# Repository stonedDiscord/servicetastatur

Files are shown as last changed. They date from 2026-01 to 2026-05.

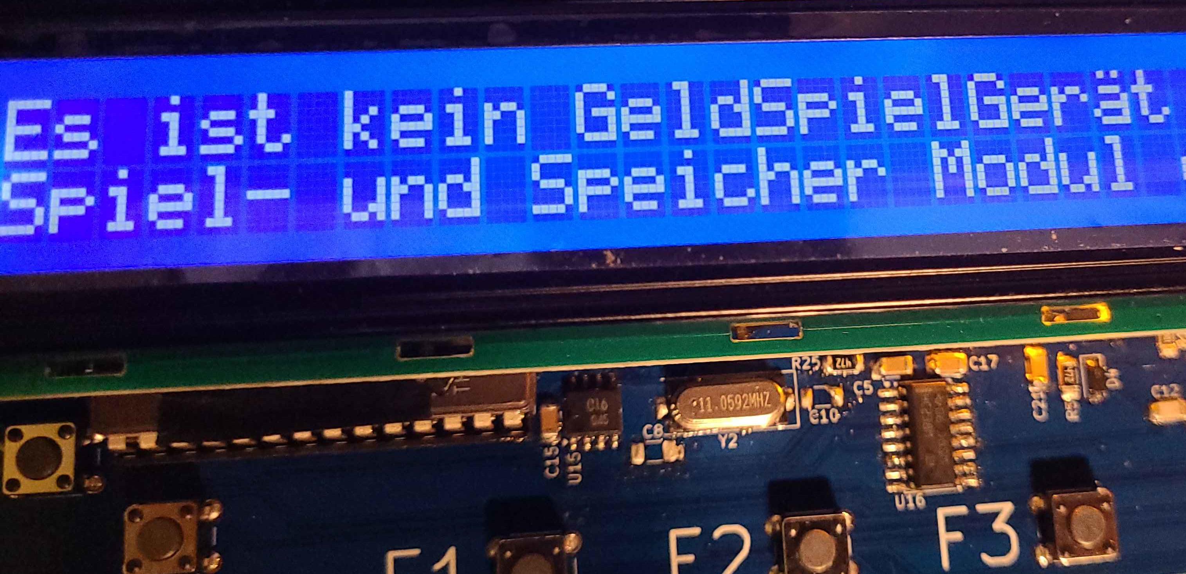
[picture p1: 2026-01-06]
photo/IMG.jpg

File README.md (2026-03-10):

# Servicetastatur

Ein Nachbau der Servicetastatur für Merkur Geräte ab Profitech 3000.

Man kann diese bei Auftragsfertigern bauen lassen,
EPROM, CPU, Display und Gehäuse müssen seperat beschafft werden.

Gehäuse ist [in Arbeit](https://github.com/stonedDiscord/servicetastatur/blob/master/case.scad),
es werden die Bibliotheken [jl_scad](https://github.com/lijon/jl_scad) und [BOSL2](https://github.com/BelfrySCAD/BOSL2) benötigt.

## Lizenz

Nachbauen und Modifizieren durch Dritte ist erlaubt, die Dokumentation inkl Schaltplan und Gerber müssen aber mit weitergegeben werden.
Die Lizenz gibt es hier auf Deutsch
https://creativecommons.org/licenses/by-sa/4.0/deed.de

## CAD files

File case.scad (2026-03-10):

include <jl_scad/box.scad>
include <jl_scad/parts.scad>
include <jl_scad/utils.scad>

$slop = 0.04;
$fn = $preview?16:48;
$attachable_dump_tree = true;
haelfte=BOT;

module button_guide(
    size = 7,
    wall = 1.2,
    h = 8,
    clearance = 0.25
){
    difference() {
        // OUTER sleeve (extends DOWN into box)
        translate([0,-1.5,0])
        cuboid(
            [size + wall*2, size + wall*2, h],
            anchor=FRONT+BOTTOM
        );

        // INNER hole
        translate([0,-0.5,-0.01])
            cuboid(
                [size + clearance, size + clearance, h + 0.02],
                anchor=FRONT+BOTTOM
            );
    }
}

sz = [183+4,57+4,24];

box_make(print=true,halves=haelfte,explode=5,hide_box=false)
{
    // rim snap
    box_shell_base_lid(sz,wall_sides=2,wall_top=1.2,rbot_inside=1,rtop_inside=1,rsides=15,rim_height=3,k=0.2,rim_snap=true) {
        // display
        box_part([TOP]) X(1.5) fwd(18) box_cutout(rect([150,15]),anchor=FRONT);

        // taster
        box_part([TOP]) X(-85) Y(14) { box_cutout(rect([6,6]),anchor=FRONT); button_guide(); } //Left
        box_part([TOP]) X(-75) Y(7)  { box_cutout(rect([6,6]),anchor=FRONT); button_guide(); } //Up
        box_part([TOP]) X(-75) Y(21) { box_cutout(rect([6,6]),anchor=FRONT); button_guide(); } //Down
        box_part([TOP]) X(-65) Y(14) { box_cutout(rect([6,6]),anchor=FRONT); button_guide(); } //Right
        
        
        box_part([TOP]) X(-34) Y(20) { box_cutout(rect([6,6]),anchor=FRONT); button_guide(); } //F1
        box_part([TOP]) X(-8)  Y(20) { box_cutout(rect([6,6]),anchor=FRONT); button_guide(); } //F2
        box_part([TOP]) X(17)  Y(20) { box_cutout(rect([6,6]),anchor=FRONT); button_guide(); } //F3
        box_part([TOP]) X(45)  Y(20) { box_cutout(rect([6,6]),anchor=FRONT); button_guide(); } //F4

        box_part([TOP]) X(77)  Y(17) { box_cutout(rect([6,6]),anchor=FRONT); button_guide(); } //OK
 
        // halter
        // lcd oben
        X(87.5)  Y(23.5) box_standoff_clamp(h=6,od=3,id=1.5,gap=2,pin_h=2);
        X(-87.5) Y(23.5) box_standoff_clamp(h=6,od=3,id=1.5,gap=2,pin_h=2);
       
        // unterschied 26.5
       
        // lcd unten
        X(87.5)  Y(-3)   box_standoff_clamp(h=16,od=3,id=1.5,gap=2,pin_h=2);
        X(-87.5) Y(-3)   box_standoff_clamp(h=16,od=3,id=1.5,gap=2,pin_h=2);
      
        // unterschied 23
      
        // board unten
        X(87.5)  Y(-26)  box_standoff_clamp(h=6,od=3,id=1.5,gap=2,pin_h=2);
        X(-87.5) Y(-26)  box_standoff_clamp(h=6,od=3,id=1.5,gap=2,pin_h=2);
        
        // kabel loch
        X(70)    Z(-6)   box_part([BACK]) box_hole(6,chamfer=1);
        
        // button wall
        X(50) Y(18) box_part([TOP],FRONT) box_wall(RIGHT,height=15,length=70,width=1,fillet=1.5,gap=0.5);
        
        // screen wall
        Y(25) box_part([TOP],FRONT) box_wall(RIGHT,height=9,length=140,width=1,fillet=1.5,gap=0.5);
        
        // screen
        box_part([TOP])
        box_preview() X(15) Y(-13) position(LEFT) cuboid([162,29,9],anchor=LEFT,edges="X");
    }
}

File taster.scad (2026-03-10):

$fn = $preview?16:48;

difference()
{
    union() {cube([6.7, 6.7, 10],center=true);
    translate([0,0,6]) cube([5.4,5.4,2],center=true);}
    translate([0,0,-4.5]) cylinder(h=1,r=2,center=true);
} 

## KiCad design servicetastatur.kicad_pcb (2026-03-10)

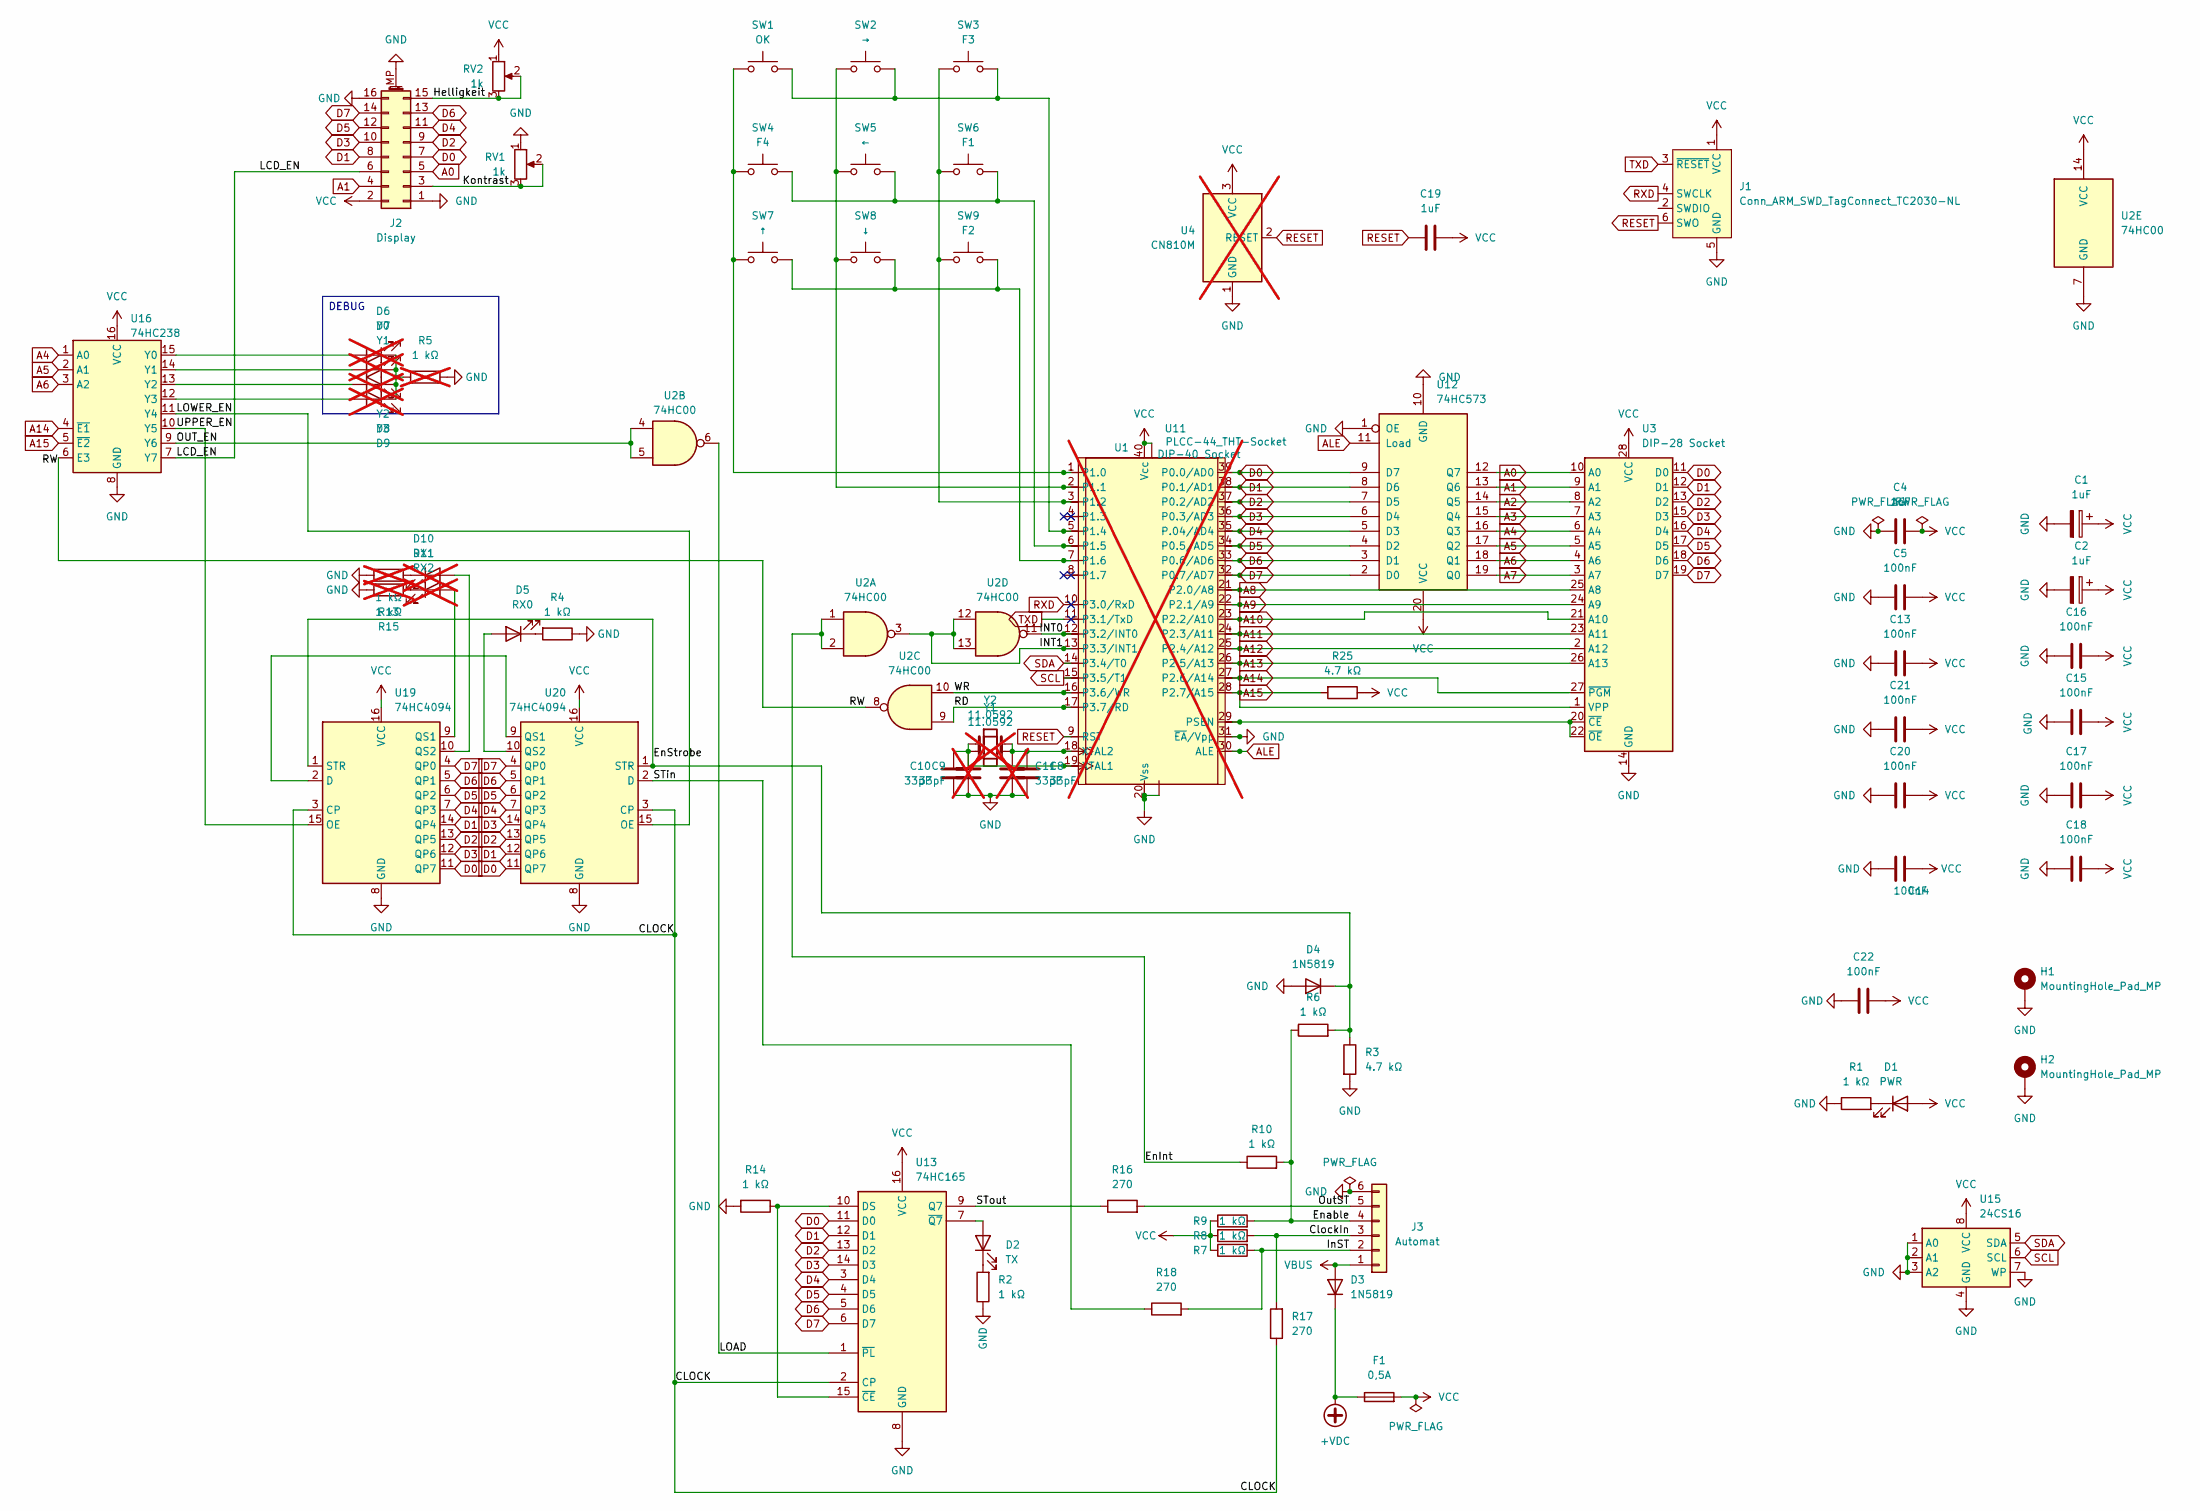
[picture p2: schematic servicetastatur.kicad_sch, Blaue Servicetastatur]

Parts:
C1, C2, C4, C19: 1uF; C_1206_3216Metric
C5, C13, C14, C15, C16, C17, C18, C20, C21, C22: 100nF; C_0603_1608Metric
C8, C10: 33pF; C_0603_1608Metric
C9, C11: 33pF; C_0603_1608Metric; not fitted
D1: PWR; LED_0805_2012Metric
D2: TX; LED_0805_2012Metric
D3, D4: 1N5819; D_SOD-123
D5: RX0; LED_0805_2012Metric
D6: Y0; LED_0805_2012Metric; not fitted
D7: Y1; LED_0805_2012Metric; not fitted
D8: Y2; LED_0805_2012Metric; not fitted
D9: Y3; LED_0805_2012Metric; not fitted
D10: RX1; LED_0805_2012Metric; not fitted
D11: RX2; LED_0805_2012Metric; not fitted
F1: 0,5A; Fuse_0805_2012Metric
H1, H2: MountingHole_Pad_MP; MountingHole 3.5mm
J1: Conn_ARM_SWD_TagConnect_TC2030-NL; Tag-Connect_TC2030-IDC-NL_2x03_P1.27mm_Vertical
J2: Display; LCDdisplay
J3: Automat; Conn01x06
R1, R2, R4, R6, R7, R8, R9, R10, R14: 1 kΩ; R_0603_1608Metric
R3, R25: 4.7 kΩ; R_0603_1608Metric
R5, R13, R15: 1 kΩ; R_0603_1608Metric; not fitted
R16, R17, R18: 270; R_0603_1608Metric
RV1, RV2: 1k; Potentiometer_Piher_PT-6-V_Vertical_Hole
SW1: OK; SW_Push_1P1T_XKB_TS-1187A
SW2: →; SW_Push_1P1T_XKB_TS-1187A
SW3: F3; SW_Push_1P1T_XKB_TS-1187A
SW4: F4; SW_Push_1P1T_XKB_TS-1187A
SW5: ←; SW_Push_1P1T_XKB_TS-1187A
SW6: F1; SW_Push_1P1T_XKB_TS-1187A
SW7: ↑; SW_Push_1P1T_XKB_TS-1187A
SW8: ↓; SW_Push_1P1T_XKB_TS-1187A
SW9: F2; SW_Push_1P1T_XKB_TS-1187A
U1: DIP-40 Socket; DIP-40_W15.24mm
U2: 74HC00; SOIC-14_3.9x8.7mm_P1.27mm
U3: DIP-28 Socket; DIP-28_W15.24mm
U4: CN810M; SOT-23; not fitted
U11: PLCC-44_THT-Socket; not fitted
U12: 74HC573; TSSOP-20_4.4x6.5mm_P0.65mm
U13: 74HC165; SOP-16_4.4x10.4mm_P1.27mm
U15: 24CS16; SO-8_3.9x4.9mm_P1.27mm
U16: 74HC238; SOIC-16W_5.3x10.2mm_P1.27mm
U19, U20: 74HC4094; SOIC-16W_5.3x10.2mm_P1.27mm
Y1: 11.0592; Crystal_HC49-U_Vertical; not fitted
Y2: 11.0592; Crystal_SMD_HC49-SD

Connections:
+VDC: D3.1 (K), F1.1
/CLOCK: R17.1, U13.2 (CP), U19.3 (CP), U20.3 (CP)
/ClockIn: J3.3, R8.2, R17.2
/EnInt: R10.1, U2.1, U2.2
/EnStrobe: D4.1 (K), R3.1, R6.2, U19.1 (STR), U20.1 (STR)
/Enable: J3.4, R6.1, R9.2, R10.2
/Helligkeit: J2.15, RV2.2, RV2.3
/INT0: U1.12 (P3.2/INT0), U2.11, U11.14 (P3.2/INT0)
/INT1: U1.13 (P3.3/INT1), U2.3, U2.12, U2.13, U11.15 (P3.3/INT1)
/InST: J3.2, R7.2, R18.2
/Kontrast: J2.3, RV1.2, RV1.3
/LCD_EN: J2.6, U16.7 (Y7)
/LOAD: U2.6, U13.1 (~PL)
/LOWER_EN: U16.11 (Y4), U20.15 (OE)
/OUT_EN: U2.4, U2.5, U16.9 (Y6)
/OutST: J3.5, R16.2
/RD: U1.17 (P3.7/RD), U2.9, U11.19 (P3.7/RD)
/RW: U2.8, U16.6 (E3)
/STin: R18.1, U20.2 (D)
/STout: R16.1, U13.9 (Q7)
/UPPER_EN: U16.10 (Y5), U19.15 (OE)
/WR: U1.16 (P3.6/WR), U2.10, U11.18 (P3.6/WR)
A0: J2.5, U3.10 (A0), U12.12 (Q7)
A1: J2.4, U3.9 (A1), U12.13 (Q6)
A2: U3.8 (A2), U12.14 (Q5)
A3: U3.7 (A3), U12.15 (Q4)
A4: U3.6 (A4), U12.16 (Q3), U16.1 (A0)
A5: U3.5 (A5), U12.17 (Q2), U16.2 (A1)
A6: U3.4 (A6), U12.18 (Q1), U16.3 (A2)
A7: U3.3 (A7), U12.19 (Q0)
A8: U1.21 (P2.0/A8), U3.25 (A8), U11.24 (P2.0/A8)
A9: U1.22 (P2.1/A9), U3.24 (A9), U11.25 (P2.1/A9)
A10: U1.23 (P2.2/A10), U3.21 (A10), U11.26 (P2.2/A10)
A11: U1.24 (P2.3/A11), U3.23 (A11), U11.27 (P2.3/A11)
A12: U1.25 (P2.4/A12), U3.2 (A12), U11.28 (P2.4/A12)
A13: U1.26 (P2.5/A13), U3.26 (A13), U11.29 (P2.5/A13)
A14: U1.27 (P2.6/A14), U3.27 (~PGM), U11.30 (P2.6/A14), U16.4 (~E1)
A15: R25.2, U1.28 (P2.7/A15), U3.1 (VPP), U11.31 (P2.7/A15), U11.34 (NIC), U16.5 (~E2)
ALE: U1.30 (ALE), U11.33 (ALE), U12.11 (Load)
D0: J2.7, U1.39 (P0.0/AD0), U3.11 (D0), U11.43 (P0.0/AD0), U12.9 (D7), U13.11 (D0), U19.11 (QP7), U20.11 (QP7)
D1: J2.8, U1.38 (P0.1/AD1), U3.12 (D1), U11.42 (P0.1/AD1), U12.8 (D6), U13.12 (D1), U19.14 (QP4), U20.12 (QP6)
D2: J2.9, U1.37 (P0.2/AD2), U3.13 (D2), U11.41 (P0.2/AD2), U12.7 (D5), U13.13 (D2), U19.13 (QP5), U20.13 (QP5)
D3: J2.10, U1.36 (P0.3/AD3), U3.15 (D3), U11.40 (P0.3/AD3), U12.6 (D4), U13.14 (D3), U19.12 (QP6), U20.14 (QP4)
D4: J2.11, U1.35 (P.04/AD4), U3.16 (D4), U11.39 (P.04/AD4), U12.5 (D3), U13.3 (D4), U19.7 (QP3), U20.7 (QP3)
D5: J2.12, U1.34 (P0.5/AD5), U3.17 (D5), U11.38 (P0.5/AD5), U12.4 (D2), U13.4 (D5), U19.6 (QP2), U20.6 (QP2)
D6: J2.13, U1.33 (P0.6/AD6), U3.18 (D6), U11.37 (P0.6/AD6), U12.3 (D1), U13.5 (D6), U19.5 (QP1), U20.5 (QP1)
D7: J2.14, U1.32 (P0.7/AD7), U3.19 (D7), U11.36 (P0.7/AD7), U12.2 (D0), U13.6 (D7), U19.4 (QP0), U20.4 (QP0)
GND: C1.2, C2.2, C4.1, C5.1, C8.1, C9.1, C10.1, C11.1, C13.1, C14.2, C15.1, C16.1, C17.1, C18.1, C20.2, C21.2, C22.1, D4.2 (A), H1.MP, H2.MP, J1.5 (GND), J2.1, J2.16, J2.MP (MountPin), J3.6, R1.1, R2.1, R3.2, R4.1, R5.1, R13.1, R14.2, R15.1, RV1.1, U1.20 (Vss), U1.31 (~EA/Vpp), U2.7 (GND), U3.14 (GND), U4.1 (GND), U11.1 (Vss1), U11.22 (Vss), U11.35 (EA), U12.1 (OE), U12.10 (GND), U13.8 (GND), U15.1 (A0), U15.2 (A1), U15.3 (A2), U15.4 (GND), U15.7 (WP), U16.8 (GND), U19.8 (GND), U20.8 (GND)
unnamed: D1.1 (K), R1.2
unnamed: D2.2 (A), U13.7 (~Q7)
unnamed: D2.1 (K), R2.2
unnamed: D5.2 (A), U20.10 (QS2)
unnamed: D5.1 (K), R4.2
unnamed: D6.2 (A), U16.15 (Y0)
unnamed: D6.1 (K), D7.1 (K), D8.1 (K), D9.1 (K), R5.2
unnamed: D7.2 (A), U16.14 (Y1)
unnamed: D8.2 (A), U16.13 (Y2)
unnamed: D9.2 (A), U16.12 (Y3)
unnamed: D10.2 (A), U19.10 (QS2)
unnamed: D10.1 (K), R13.2
unnamed: D11.2 (A), U19.9 (QS1)
unnamed: D11.1 (K), R15.2
unnamed: SW1.1, SW4.1, SW7.1, U1.1 (P1.0), U11.2 (P1.0)
unnamed: SW2.1, SW5.1, SW8.1, U1.2 (P1.1), U11.3 (P1.1)
unnamed: SW3.1, SW6.1, SW9.1, U1.3 (P1.2), U11.4 (P1.2)
unnamed: SW1.2, SW2.2, SW3.2, U1.5 (P1.4), U11.6 (P1.4)
unnamed: SW4.2, SW5.2, SW6.2, U1.6 (P1.5), U11.7 (P1.5)
unnamed: SW7.2, SW8.2, SW9.2, U1.7 (P1.6), U11.8 (P1.6)
unnamed: U1.29 (PSEN), U3.20 (~CE), U3.22 (~OE), U11.32 (PSEN)
unnamed: C9.2, C10.2, U1.19 (XTAL1), U11.21 (XTAL1), Y1.1, Y2.1
unnamed: C8.2, C11.2, U1.18 (XTAL2), U11.20 (XTAL2), Y1.2, Y2.2
unnamed: R14.1, U13.10 (DS), U13.15 (~CE)
unnamed: U19.2 (D), U20.9 (QS1)
RESET: C19.1, J1.6 (SWO), U1.9 (RST), U4.2 (RESET), U11.10 (RST)
RXD: J1.4 (SWCLK), U1.10 (P3.0/RxD)
SCL: U1.15 (P3.5/T1), U11.17 (P3.5/T1), U15.6 (SCL)
SDA: U1.14 (P3.4/T0), U11.16 (P3.4/T0), U15.5 (SDA)
TXD: J1.3 (~RESET), U1.11 (P3.1/TxD)
VBUS: D3.2 (A), J3.1
VCC: C1.1, C2.1, C4.2, C5.2, C13.2, C14.1, C15.2, C16.2, C17.2, C18.2, C19.2, C20.1, C21.1, C22.2, D1.2 (A), F1.2, J1.1 (VCC), J2.2, R7.1, R8.1, R9.1, R25.1, RV2.1, U1.40 (Vcc), U2.14 (VCC), U3.28 (VCC), U4.3 (VCC), U11.44 (Vcc), U12.20 (VCC), U13.16 (VCC), U15.8 (VCC), U16.16 (VCC), U19.16 (VCC), U20.16 (VCC)

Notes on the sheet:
DEBUG

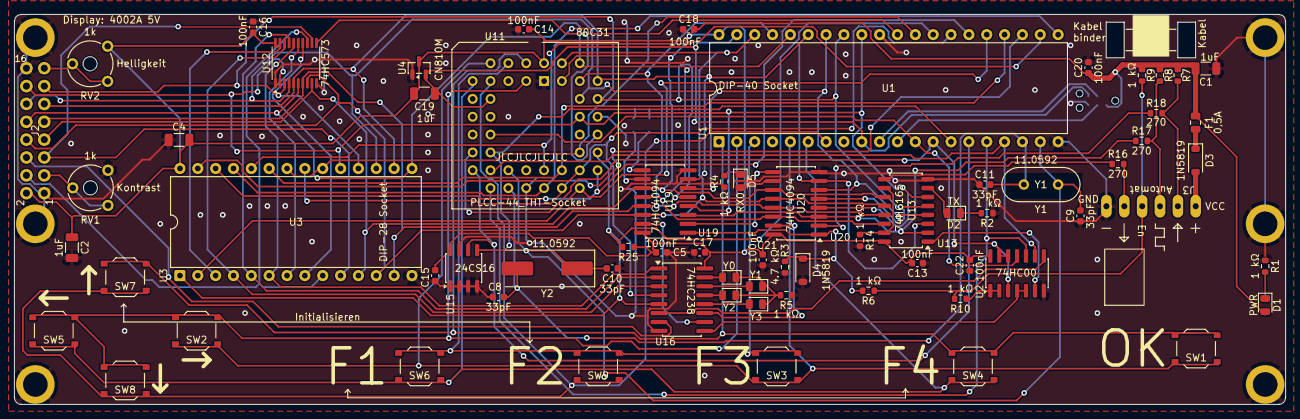
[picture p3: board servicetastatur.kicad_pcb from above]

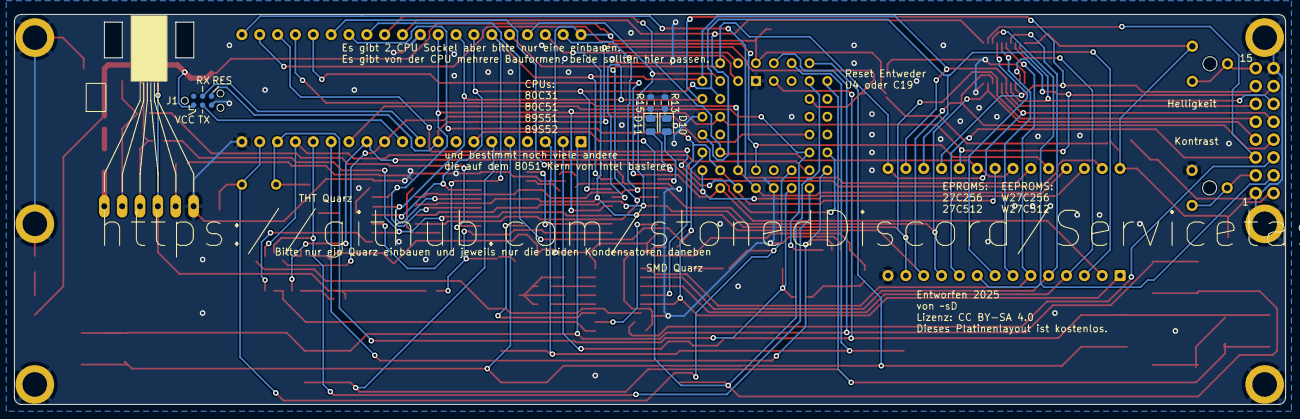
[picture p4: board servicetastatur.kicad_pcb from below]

Board: 2 copper layers, 180.9 x 55.5 mm, 76 parts (5 on the bottom side), 80 nets.

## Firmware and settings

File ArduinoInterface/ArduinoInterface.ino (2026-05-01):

// Servicetastatur-Interface
// J3 (top to bottom): VBUS - InST - ClockIn - Enable - STout - GND
// TX (Board to Machine): U13 74HC165 (8-bit PISO, no swap, no pin reversal)
// RX (Machine to Board): U20+U19 74HC4094 Cascade (16-bit SIPO, swap D1/D3 on U19, pins reversed QP7=D0)

const int PIN_TX  = 5;  // Arduino Output: InST / 2STin at U20 (Board RX)
const int PIN_EN  = 2;  // Arduino Input: EnStrobe from machine (INT0)
const int PIN_CLK = 3;  // Arduino Input: Clock from machine (INT1)
const int PIN_RX  = 4;  // Arduino Input: STout from U13 (Board TX)

// TX from board perspective (sniffed by Arduino from U13)
volatile uint16_t txShift   = 0;
volatile uint16_t txLatched = 0;
volatile bool     txReady   = false;

// RX from board perspective (driven by Arduino into U20/U19)
volatile uint16_t rxData   = 0x0000;
volatile int8_t   rxBitPos = 15;

// Helper to reverse bits in a byte
uint8_t reverseByte(uint8_t x) {
  x = ((x & 0x55) << 1) | ((x & 0xAA) >> 1);
  x = ((x & 0x33) << 2) | ((x & 0xCC) >> 2);
  x = (x << 4) | (x >> 4);
  return x;
}

// Process data transmitted by the board (from U13)
uint8_t processTX(uint16_t val) {
  // U13 has no swap and no reversal.
  // After 16 clocks (MSB first), the 8 bits of data end up in the upper byte.
  return (uint8_t)((val >> 8) & 0xFF);
}

// Prepare data for the board to receive (into U19/U20)
uint16_t prepareRX(uint16_t val) {
  uint8_t low  = val & 0xFF;
  uint8_t high = (val >> 8) & 0xFF;

  // 1. D1 and D3 are swapped on U19 (RX path)
  uint8_t d1 = (low >> 1) & 1;
  uint8_t d3 = (low >> 3) & 1;
  low &= ~((1 << 1) | (1 << 3));
  low |= (d3 << 1) | (d1 << 3);

  // 2. Pins are reversed on U19/U20 (QP7=D0)
  low  = reverseByte(low);
  high = reverseByte(high);

  // U19 (low byte) is at the end of the shift chain.
  // Bits are shifted MSB first (bit 15 down to 0).
  // The first 8 bits shifted end up in U19, the next 8 in U20.
  return ((uint16_t)low << 8) | high;
}

void isr_clock() {
  if (digitalRead(PIN_CLK) == HIGH) {
    // Rising edge: read Board TX bit, advance Board RX bit pointer
    txShift = (txShift << 1) | (uint16_t)digitalRead(PIN_RX);
    if (rxBitPos > 0) rxBitPos--;
  } else {
    // Falling edge: output next Board RX bit (stable before next rising edge)
    digitalWrite(PIN_TX, (rxData >> rxBitPos) & 1);
  }
}

void isr_enable() {
  // Rising edge: secure TX frame, reset RX and TX for next frame
  txLatched = txShift;
  txReady   = true;
  txShift   = 0;
  rxBitPos  = 15;
  digitalWrite(PIN_TX, (rxData >> 15) & 1);
}

void setup() {
  Serial.begin(115200);
  pinMode(PIN_TX,  OUTPUT);
  pinMode(PIN_EN,  INPUT);
  pinMode(PIN_CLK, INPUT);
  pinMode(PIN_RX,  INPUT);
  digitalWrite(PIN_TX, (rxData >> 15) & 1);
  attachInterrupt(digitalPinToInterrupt(PIN_EN),  isr_enable, RISING);
  attachInterrupt(digitalPinToInterrupt(PIN_CLK), isr_clock,  CHANGE);
}

void loop() {
  if (txReady) {
    noInterrupts();
    uint16_t val = txLatched;
    txReady = false;
    interrupts();

    // Extract raw byte from Board TX stream
    uint8_t txValue = processTX(val);

    Serial.print("TX: 0x");
    if (txValue < 0x10) Serial.print("0");
    Serial.println(txValue, HEX);
  }

  // Receive hex value via Serial to send to Board RX, e.g. "A5"
  if (Serial.available()) {
    String s = Serial.readStringUntil('\n');
    s.trim();
    if (s.length() > 0) {
      uint16_t val  = (uint16_t)strtoul(s.c_str(), nullptr, 16);
      uint16_t prepared = prepareRX(val);
      noInterrupts();
      rxData   = prepared;
      rxBitPos = 15;
      digitalWrite(PIN_TX, (rxData >> 15) & 1);
      interrupts();
      Serial.print("RX: 0x");
      Serial.print(val, HEX);
      Serial.print(" -> prepared: 0x");
      Serial.println(prepared, HEX);
    }
  }
}

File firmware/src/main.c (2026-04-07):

/*
 * Keypad test
 * Displays the current keypad state on the connected LCD
 */

 /*
#undef __SDCC_mcs51
#include "lint.h"
#define __SDCC_mcs51
*/

#if defined(STC12C5AXXS2)
#include <stc12.h>
#elif defined(STC89C5XRX)
#include <stc89.h>
#elif defined(AT89S51)
#include <at89x51.h>
#elif defined(AT89S52)
#include <at89x52.h>
#elif defined(Generic8052)
#include "Generic8052.h"
#else // Assume Generic8051
#include "Generic8051.h"
#endif

#include <stdint.h>

#include "hd44780.h"

// NC
__xdata volatile uint8_t* const GSG1_W  = (__xdata uint8_t*)0x0010;
__xdata volatile uint8_t* const GSG2_W  = (__xdata uint8_t*)0x0020;
__xdata volatile uint8_t* const GSG3_W  = (__xdata uint8_t*)0x0030;

// upper in
__xdata volatile uint8_t* const GSG4_R  = (__xdata uint8_t*)0x0040;
// lower in
__xdata volatile uint8_t* const GSG5_R  = (__xdata uint8_t*)0x0050;

//out
__xdata volatile uint8_t* const GSG6_W  = (__xdata uint8_t*)0x0060;

// lcd
__xdata volatile uint8_t* const LCD_CMD_W  = (__xdata uint8_t*)0x0070;
__xdata volatile uint8_t* const LCD_CMD_R  = (__xdata uint8_t*)0x0071;
__xdata volatile uint8_t* const LCD_DATA_W = (__xdata uint8_t*)0x0072;
__xdata volatile uint8_t* const LCD_DATA_R = (__xdata uint8_t*)0x0073;

static void spin_delay(uint16_t delay)
{
    uint16_t i;
    for (i = 0; i < delay; i++)
        ;
}

static void lcd_wait_ready(void)
{
    while (*LCD_CMD_R & HD44780_BUSY)
        ;
}

static void lcd_cmd(uint8_t cmd)
{
    lcd_wait_ready();
    *LCD_CMD_W = cmd;
}

static void lcd_putc(char c)
{
    lcd_wait_ready();
    *LCD_DATA_W = c;
}

static void lcd_puts(const char *s)
{
    while (*s)
    {
        lcd_putc(*s++);
    }
}

// Keypad scan function
uint8_t scan_kbd(void)
{
    uint8_t row_state;
    uint8_t key_count = 0;
    uint8_t key_code = 0;
    uint8_t column_input;
    P1 = 0xfb; // P1.2 column 3, F1, F2, F3
    row_state = P1 & 0x70;
    if (row_state == 0x50)
    {
        key_count = 1;
        key_code = 1;
    } // F1
    else if (row_state == 0x30)
    {
        key_count = 1;
        key_code = 2;
    } // F2
    else if (row_state == 0x60)
    {
        key_count = 1;
        key_code = 3;
    } // F3

    P1 = 0xfd; // P1.1 column 2, Left, Down, Right
    row_state = P1 & 0x70;
    if (row_state == 0x50)
    {
        key_count++;
        key_code = 7;
    } // Left
    else if (row_state == 0x30)
    {
        key_count++;
        key_code = 8;
    } // Down
    else if (row_state == 0x60)
    {
        key_count++;
        key_code = 9;
    } // Right

    P1 = 0xfe; // P1.0 column 1, F4, Up, OK
    row_state = P1;
    column_input = row_state & 0x70;
    if (column_input == 0x50)
    {
        if (key_code == 1)
            key_code = 0x10; // F1 + F4
        else
        {
            key_code = 4;
            key_count++;
        } // F4
    }
    else if (column_input == 0x30)
    {
        if (key_code == 2)
            key_code = 0x11; // F2 + Up
        else
        {
            key_count++;
            key_code = 5;
        } // Up
    }
    else if (column_input == 0x60)
    {
        key_count++;
        key_code = 6;
    } // OK

    P1 = 0xff;
    if (key_count != 1)
        key_code = 0; // No key or multiple keys pressed
    return key_code;
}

// Convert a small number to decimal string and display it
static void lcd_putnum(uint8_t n)
{
    char buf[4];
    char *p = buf + sizeof(buf) - 1;
    *p = '\0';
    if (n == 0)
    {
        *--p = '0';
    }
    else
    {
        while (n > 0)
        {
            *--p = '0' + (n % 10);
            n /= 10;
        }
    }
    lcd_puts(p);
}

// Convert key code to key name
static const char *key_code_to_name(uint8_t key_code)
{
    switch (key_code)
    {
    case 0x01:
        return "F1";
    case 0x02:
        return "F2";
    case 0x03:
        return "F3";
    case 0x04:
        return "F4";
    case 0x05:
        return "HOCH";
    case 0x06:
        return "OK";
    case 0x07:
        return "Links";
    case 0x08:
        return "RUNTER";
    case 0x09:
        return "RECHTS";
    case 0x10:
        return "F1+F4";
    case 0x11:
        return "F2+HOCH";
    default:
        return "None";
    }
}

void read_gsg(void)
{
    uint8_t direction = 1;
    uint8_t gsg_command = 0;
    if (direction == 0x03)
    {
        direction = 0x02;
    }
    gsg_command = *GSG5_R >> 1 & 7;
    if (direction == 0x01)
    {
        if ((*GSG5_R & 1) != 0)
        {
            if ((*GSG4_R & 0x20) == 0)
            {
                lcd_putc((*GSG5_R >> 4) + *GSG4_R * 0x10);
            }
            else
            {
                lcd_cmd((*GSG5_R >> 4) + *GSG4_R * 0x10);
            }
        }
    }
}

// Interrupt handler External 0
void INT0_ISR(void) __interrupt(0)
{
    EA = 0;
    // lcd_cmd(HD44780_CMD_SET_DDRAM_ADDR | (HD44780_LINE2_ADDR + 15));
    // lcd_puts("INT0");
    read_gsg();
}

// Interrupt handler External 1
void INT1_ISR(void) __interrupt(2)
{
    EA = 0;
    // lcd_cmd(HD44780_CMD_SET_DDRAM_ADDR | (HD44780_LINE1_ADDR + 15));
    // lcd_puts("INT1");
    read_gsg();
}

void main(void)
{
    AUXR = 0x02; // Use external memory
    reset_all();
    EX1 = 1;

    uint16_t rend = 0;

    // Line 1: title
    lcd_cmd(HD44780_CMD_SET_DDRAM_ADDR | HD44780_LINE1_ADDR | 0x00);
    lcd_puts("Keypad Test        ");
    while (1)
    {
        uint8_t key = scan_kbd();

        lcd_cmd(HD44780_CMD_SET_DDRAM_ADDR | HD44780_LINE2_ADDR | 0x00); // Line 2
        lcd_puts("Key:          ");                                      // clear old value with spaces
        lcd_cmd(HD44780_CMD_SET_DDRAM_ADDR | HD44780_LINE2_ADDR | 0x05); // move cursor after "Key: "
        lcd_puts(key_code_to_name(key));
        rend++;
        *GSG6_W = (uint8_t)(rend & 0x00FF);
        EA = 1;
        spin_delay(100);
        EA = 0;
    }
}

void reset_all()
{
    reset_hw();
    reset_int();
    reset_timer();
    sfr_setup();
    reset_vars();
    lcd_init();
}

static void lcd_init(void)
{
    lcd_cmd(HD44780_CMD_FUNCTION_SET | HD44780_FUNCTION_8BIT | HD44780_FUNCTION_2LINE | HD44780_FUNCTION_5X7DOTS);
    lcd_cmd(HD44780_CMD_DISPLAY_CTRL | HD44780_DISPLAY_ON | HD44780_DISPLAY_CURSOR_OFF | HD44780_DISPLAY_BLINK_OFF);
    lcd_cmd(HD44780_CMD_ENTRY_MODE | HD44780_ENTRY_LTR);
    lcd_cmd(HD44780_CMD_CLEAR);
}

void reset_hw()
{
    P0 = 0xff;
    P1 = 0xff;
    P1 = 0x00;
    P2 = 0xff;
    P3 = 0xff;
    *GSG2_W = 0xff;
    *GSG3_W = 0xff;
    *GSG6_W = 0x00;
    return;
}

void reset_int()
{
    EA = 0;
    ET0 = 0;
    TR0 = 0;
    ES = 0;
    EX0 = 0;
    EX1 = 0;
    TCON = 0;
    return;
}

void reset_timer()
{
    TR1 = 0;
    TH1 = 0;
    TL1 = 0;
    return;
}

void reset_vars()
{
    return;
}

void sfr_setup()
{
    TMOD = 0x21;
    TH1 = 0xfc;
    TR1 = 1;
    SCON = 0x42;
    ES = 0;
    REN = 1;
    TI = 0;
    return;
}

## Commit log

2023-09-06 war nochmal kleiner
    [servicetastatur.kicad_pcb]
2023-09-06 wieder groesser
    [servicetastatur.kicad_pcb]
2023-09-06 elkos gedreht
    [servicetastatur.kicad_pcb]
2023-09-06 i mag ned mehr
    [servicetastatur.kicad_pcb, servicetastatur.kicad_sch]
2024-10-07 2024 update
    [servicetastatur.kicad_pcb, servicetastatur.kicad_sch]
2024-10-07 shift register
    [servicetastatur.kicad_pcb, servicetastatur.kicad_sch]
2024-11-08 so hab bestellt
    [servicetastatur.kicad_pcb, servicetastatur.kicad_sch]
2025-02-09 lcd gefixt
    [servicetastatur.kicad_pcb, servicetastatur.kicad_sch]
2025-03-11 replace reset circuit with cap
    [servicetastatur.kicad_pcb, servicetastatur.kicad_sch]
2025-03-15 bestellt 2
    [servicetastatur.kicad_pcb, servicetastatur.kicad_sch]
2025-03-30 kontrast gnd
    [servicetastatur.kicad_pcb, servicetastatur.kicad_sch]
2025-05-19 reset chip
    [servicetastatur.kicad_pcb, servicetastatur.kicad_sch]
2025-07-09 pin names
    [servicetastatur.kicad_pcb, servicetastatur.kicad_sch]
2025-12-18 schematic kibot file
2025-12-18 screw docker
2026-01-06 2026 update
    [servicetastatur.kicad_pcb, servicetastatur.kicad_sch]
2026-01-07 led blink
2026-01-08 arduino test
2026-01-23 debug led
    [servicetastatur.kicad_pcb, servicetastatur.kicad_sch]
2026-02-07 weg vom crystal
    [servicetastatur.kicad_pcb]
2026-02-07 Squashed commit of the following:
    commit 8158f11a7876317cc5d9a1b01b5ff45f2dccbbc1
    Author: stonedDiscord <Tukz@gmx.de>
    Date: Sat Feb 7 17:56:19 2026 +0100
    arduino header and move to cpp
    commit 4ade06e093e7fc0500cbfabf0a8437dced51609a
    Author: stonedDiscord <Tukz@gmx.de>
    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
2026-03-10 no stl
2026-03-10 switch to stc
2026-03-10 hide plcc pins
    [servicetastatur.kicad_sch]
2026-03-10 tag connect
    [servicetastatur.kicad_pcb, servicetastatur.kicad_sch]
2026-03-10 taster tab
    [taster.scad]
2026-03-10 case lib
2026-04-07 2 solutions 1 problem
    [main.c]

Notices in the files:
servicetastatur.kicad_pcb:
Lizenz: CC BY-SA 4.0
